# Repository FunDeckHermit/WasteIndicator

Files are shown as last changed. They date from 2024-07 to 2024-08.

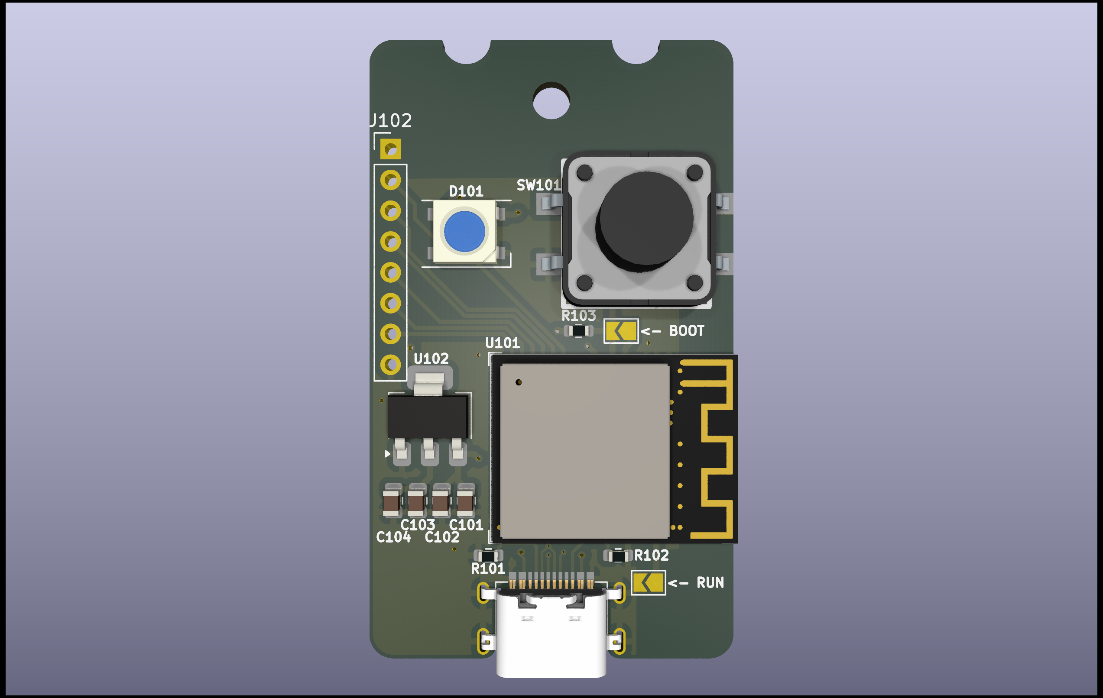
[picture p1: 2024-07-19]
KiCAD files/Exports/Waste Indicator Front.png

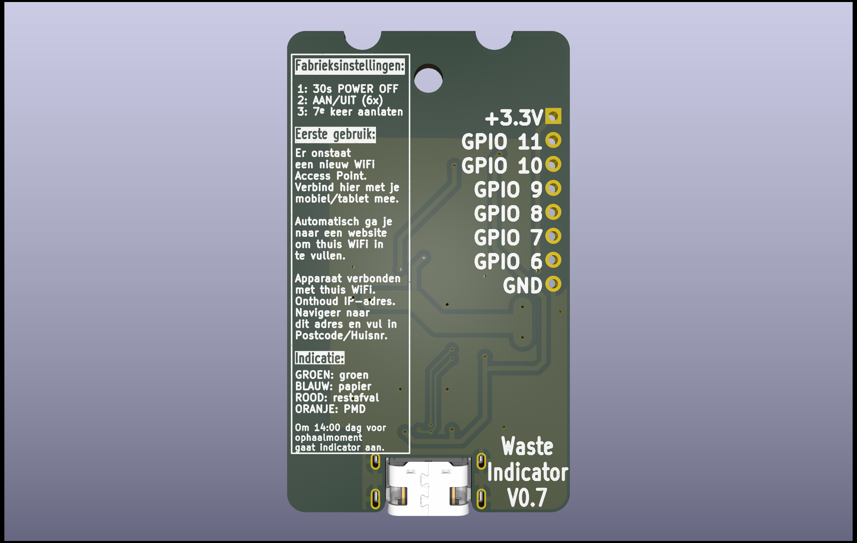
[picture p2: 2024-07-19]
KiCAD files/Exports/Waste Indicator Back.png

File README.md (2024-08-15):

# Waste Indicator
Scripts that modify Tasmota to interact with the Ximmio waste API. The color of an LED is set the day before a pickup date. It should also be easy to integrate into Home Assistant. 




## What it does:
* Sets the color of an RGB LED on the day before a pickup date
* Hides the RGB LED controls from Tasmota's main page
* Adds a form to set home adres
* Queries Ximmio's API to get the uniqueID of the adres
* Queries pickup dates every 12 hours
* Add a button to turn the LED off
* Save configuration during reset
* Reset configuration when holding button 8 seconds

## To-do
* Integrate into Home Assistant
* Don't use the companyCode of my local waste collector
* Test with a Tasmota compatible RGB light bulb
* Blink LED on first boot

# How to flash
Use a Webserial based ESP32 flasher or use ESPtool from the command line to flash the PCB.
First solder the "Boot" jumper, then hold the button to get the ESP32 into boot mode.

`esptool --port /dev/ttyACM0 erase_flash`   
`esptool --port /dev/ttyACM0 write_flash 0x0 tasmota32s2.factory.bin`

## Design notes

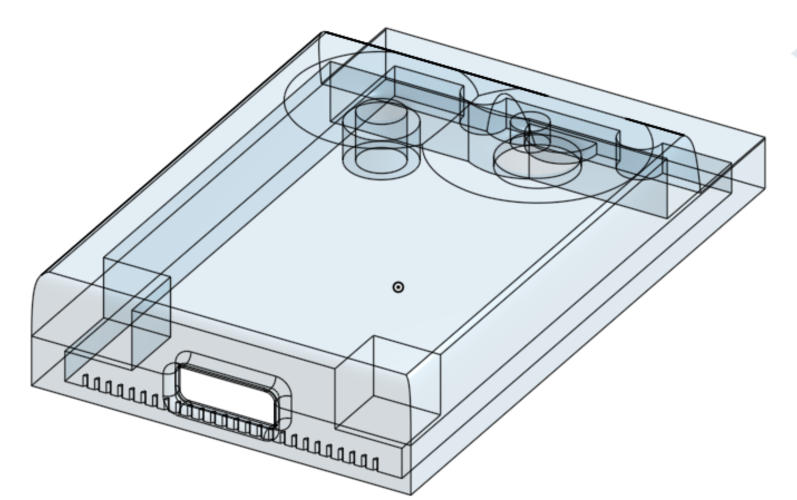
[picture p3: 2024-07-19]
OnShape Housing/Housing.png

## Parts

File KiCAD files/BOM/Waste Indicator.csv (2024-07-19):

Designator | Comment | Footprint | MF | MP | Quantity
C101, C102, C103, C104 | 1uF | C_0805_2012Metric | TAIYO YUDEN | MSASU21GSB7105KTNA01 | 4
R101, R102, R103 | 5K1 | R_0603_1608Metric | YAGEO | RC0603FR-075K1L | 3
D101 | SK6812 | LED_SK6812_PLCC4_5.0x5.0mm_P3.2mm | Adafruit | 1655 | 1
U101 | ESP32-S2-MINI-1 | ESP32-S2-MINI-1 | Esperrif | ESP32-S2-MINI-1-N4R2 | 1
U102 | AMS1117-3.3 | SOT-223-3_TabPin2 |  |  | 1
SW101 | 4,30172E+11 | btn_momentary_430172085816 | Wurth Elektronik | 4,30172E+11 | 1
J101 | USB4500-03-0-A | USB_C_Receptacle_USB4500-03-0-A | Global Connector Technology | USB4500-03-0-A | 1
J102 | Conn_01x08_Socket | PinHeader_1x08_P2.54mm_Vertical |  |  | 1

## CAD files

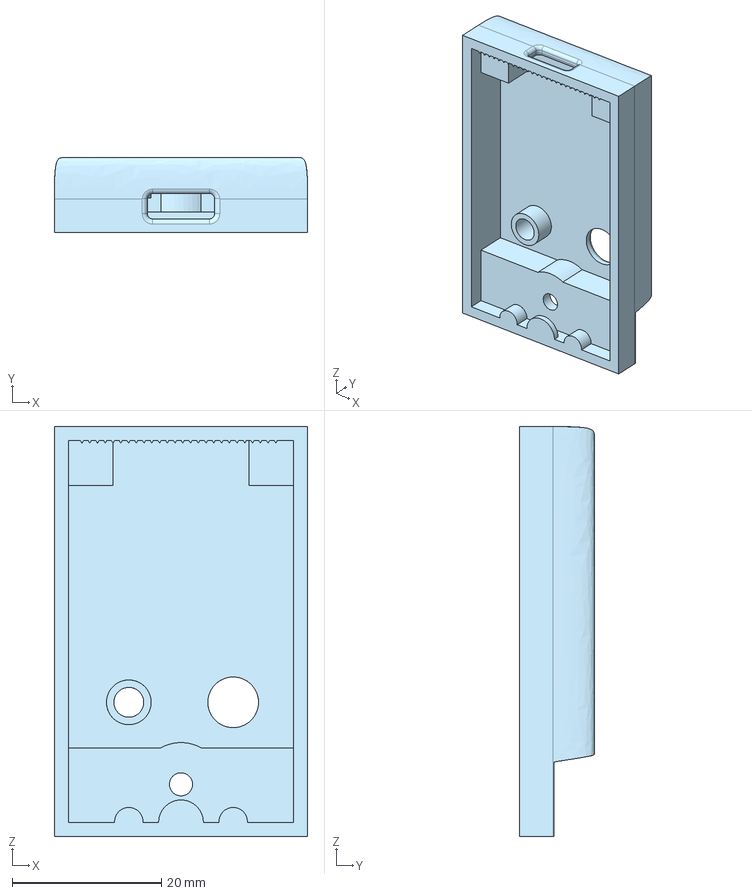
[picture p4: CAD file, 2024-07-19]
OnShape Housing/Housing.step
34.0 x 10.0 x 55.0 mm

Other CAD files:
OnShape Housing/Housing.stl

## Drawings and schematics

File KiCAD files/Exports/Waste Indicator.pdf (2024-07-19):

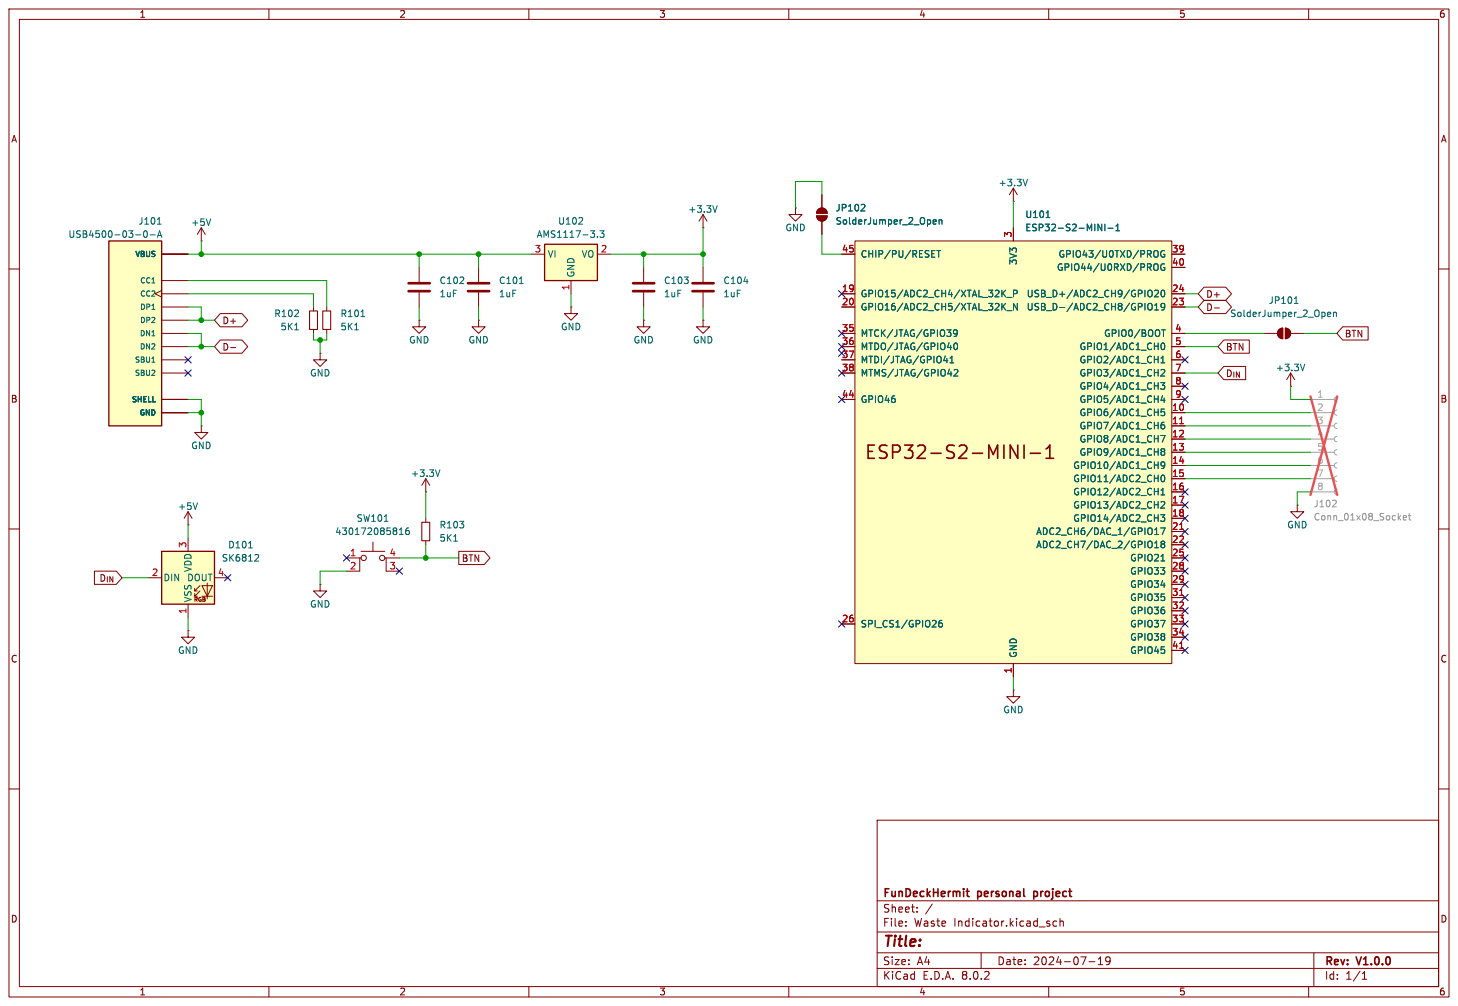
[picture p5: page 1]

3 GPIO35 31 GPIO36 32 GPIO37 33 GPIO38 34 MTCK/JTAG/GPIO39 35 MTDO/JTAG/GPIO40 36 MTDI/JTAG/GPIO41 37 MTMS/JTAG/GPIO42 38 GPIO43/U0TXD/PROG 39 GPIO0/BOOT 4 GPIO44/U0RXD/PROG 40 GPIO45 41 GPIO1/ADC1_CH0 5 GPIO2/ADC1_CH1 6 GPIO3/ADC1_CH2 7 GPIO4/ADC1_CH3 8 GPIO5/ADC1_CH4 9 U101 ESP32-S2-MINI-1 +5VGND GND GND

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

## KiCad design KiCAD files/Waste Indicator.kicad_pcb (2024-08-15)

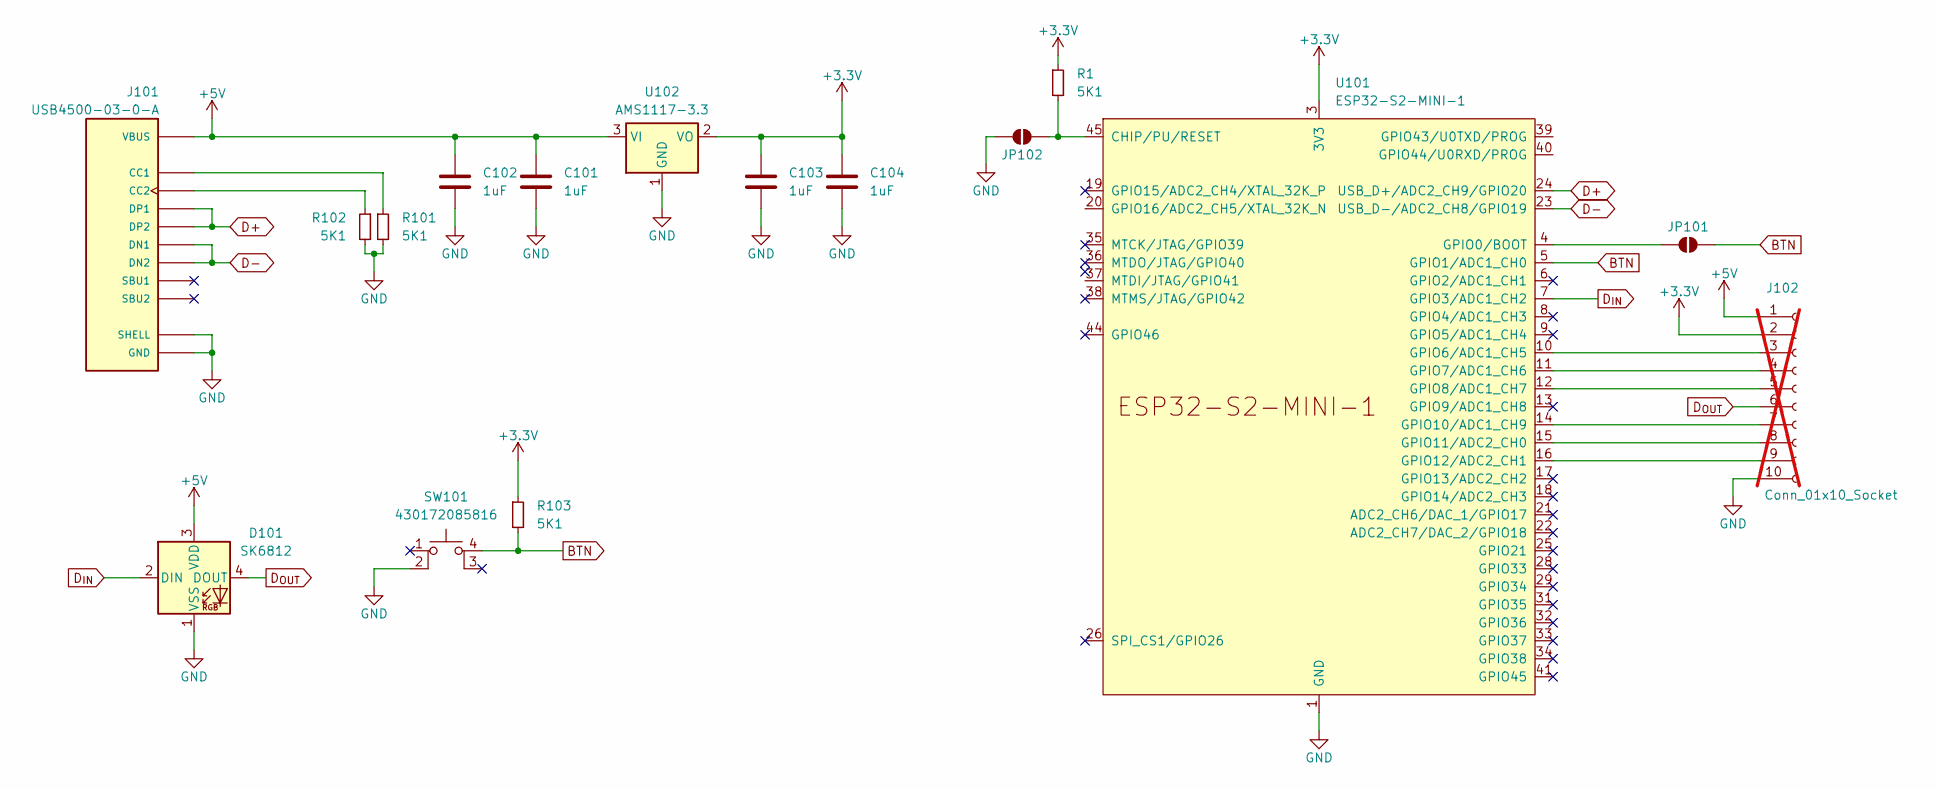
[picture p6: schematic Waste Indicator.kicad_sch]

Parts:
C101, C102, C103, C104: 1uF; C_0805_2012Metric
D101: SK6812; LED_SK6812_PLCC4_5.0x5.0mm_P3.2mm
J101: USB4500-03-0-A; USB_C_Receptacle_USB4500-03-0-A
J102: Conn_01x10_Socket; PinHeader_1x10_P2.54mm_Vertical; not fitted
JP101, JP102: SolderJumper_2_Open; SolderJumper-2_P1.3mm_Open_TrianglePad1.0x1.5mm
R1, R101, R102, R103: 5K1; R_0603_1608Metric
SW101: 430172085816; btn_momentary_430172085816
U101: ESP32-S2-MINI-1
U102: AMS1117-3.3; SOT-223-3_TabPin2

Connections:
+3.3V: C103.1, C104.1, J102.2, R1.1, R103.1, U101.3 (3V3), U102.2 (VO)
+5V: C101.1, C102.1, D101.3 (VDD), J101.A4 (VBUS), J101.A9 (VBUS), J101.B4 (VBUS), J101.B9 (VBUS), J102.1, U102.3 (VI)
BTN: JP101.2 (B), R103.2, SW101.4, U101.5 (GPIO1/ADC1_CH0)
D+: J101.A6 (DP1), J101.B6 (DP2), U101.24 (USB_D+/ADC2_CH9/GPIO20)
D-: J101.A7 (DN1), J101.B7 (DN2), U101.23 (USB_D-/ADC2_CH8/GPIO19)
D_{IN}: D101.2 (DIN), U101.7 (GPIO3/ADC1_CH2)
D_{OUT}: D101.4 (DOUT), J102.6
GND: C101.2, C102.2, C103.2, C104.2, D101.1 (VSS), J101.A1 (GND), J101.A12 (GND), J101.B1 (GND), J101.B12 (GND), J101.S1 (SHELL), J102.10, JP102.2 (B), R101.2, R102.2, SW101.2, U101.1 (GND), U101.2 (GND), U101.30 (GND), U101.42 (GND), U101.43 (GND), U101.46 (GND), U101.47 (GND), U101.48 (GND), U101.49 (GND), U101.50 (GND), U101.51 (GND), U101.52 (GND), U101.53 (GND), U101.54 (GND), U101.55 (GND), U101.56 (GND), U101.57 (GND), U101.58 (GND), U101.59 (GND), U101.60 (GND), U101.61 (GND), U101.62 (GND), U101.63 (GND), U101.64 (GND), U101.65 (GND), U102.1 (GND)
unnamed: J101.A5 (CC1), R101.1
unnamed: J101.B5 (CC2), R102.1
unnamed: J102.3, U101.10 (GPIO6/ADC1_CH5)
unnamed: J102.4, U101.11 (GPIO7/ADC1_CH6)
unnamed: J102.5, U101.12 (GPIO8/ADC1_CH7)
unnamed: J102.7, U101.14 (GPIO10/ADC1_CH9)
unnamed: J102.8, U101.15 (GPIO11/ADC2_CH0)
unnamed: J102.9, U101.16 (GPIO12/ADC2_CH1)
unnamed: JP101.1 (A), U101.4 (GPIO0/BOOT)
unnamed: JP102.1 (A), R1.2, U101.45 (CHIP/PU/RESET)

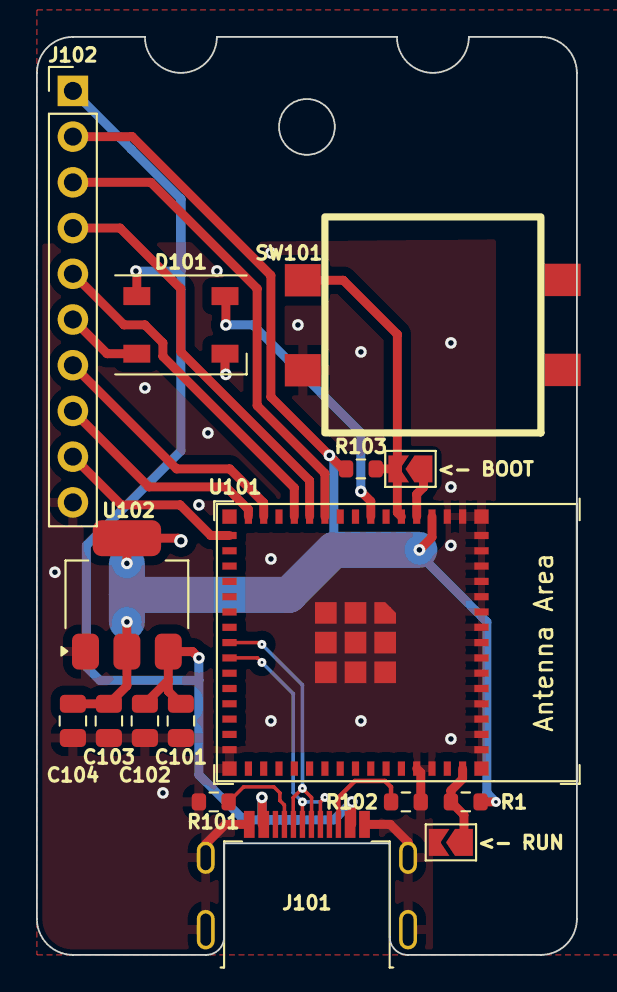
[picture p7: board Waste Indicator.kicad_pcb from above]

Board: 2 copper layers, 30.0 x 51.0 mm, 16 parts (0 on the bottom side), 18 nets.

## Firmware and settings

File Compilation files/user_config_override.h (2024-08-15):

/*
  user_config_override.h - user configuration overrides my_user_config.h for Tasmota

  Copyright (C) 2021  Theo Arends

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
  You should have received a copy of the GNU General Public License
  along with this program.  If not, see <http://www.gnu.org/licenses/>.
*/

#ifndef _USER_CONFIG_OVERRIDE_H_
#define _USER_CONFIG_OVERRIDE_H_

/*****************************************************************************************************\
 * USAGE:
 *   To modify the stock configuration without changing the my_user_config.h file:
 *   (1) copy this file to "user_config_override.h" (It will be ignored by Git)
 *   (2) define your own settings below
 *
 ******************************************************************************************************
 * ATTENTION:
 *   - Changes to SECTION1 PARAMETER defines will only override flash settings if you change define CFG_HOLDER.
 *   - Expect compiler warnings when no ifdef/undef/endif sequence is used.
 *   - You still need to update my_user_config.h for major define USE_MQTT_TLS.
 *   - All parameters can be persistent changed online using commands via MQTT, WebConsole or Serial.
\*****************************************************************************************************/

//#define FIRMWARE_LITE

#undef  MY_LANGUAGE
#define MY_LANGUAGE            nl_NL           // Dutch in the Nederland

#undef MQTT_BUTTONS
#define MQTT_BUTTONS           true

#undef KEY_HOLD_TIME
#define KEY_HOLD_TIME 8

#undef APP_BLINKTIME
#define APP_BLINKTIME 3

#undef  USE_HOME_ASSISTANT
#define USE_HOME_ASSISTANT

#undef HOME_ASSISTANT_DISCOVERY_PREFIX
#define HOME_ASSISTANT_DISCOVERY_PREFIX   "homeassistant"  // Home Assistant discovery prefix

#undef HOME_ASSISTANT_LWT_TOPIC
#define HOME_ASSISTANT_LWT_TOPIC   "homeassistant/status"  // home Assistant Birth and Last Will Topic (default = homeassistant/status)

#undef HOME_ASSISTANT_LWT_SUBSCRIBE
#define HOME_ASSISTANT_LWT_SUBSCRIBE    true               // Subscribe to Home Assistant Birth and Last Will Topic (default = true)

#undef USE_WS2812_HARDWARE
#define USE_WS2812_HARDWARE  NEO_HW_SK6812

#undef USE_WS2812_CTYPE
#define USE_WS2812_CTYPE     NEO_GRBW

#undef USE_BERRY_DEBUG
#define USE_BERRY_DEBUG

#undef USER_TEMPLATE
#define USER_TEMPLATE "{\"NAME\":\"Vuilnis Indicator\",\"GPIO\":[32,1,1,1376,1,1,1,1,1,1,1,1,1,1,1,1,0,1,1,1,0,1,1,1,0,0,0,0,1,1,1,1,1,0,0,1],\"FLAG\":0,\"BASE\":1}"  // [Template] Set JSON template

#undef MODULE
#define MODULE USER_MODULE

#undef FALLBACK_MODULE
#define FALLBACK_MODULE USER_MODULE

#undef PROJECT
#define PROJECT "VuilnisIndicator"

#endif  // _USER_CONFIG_OVERRIDE_H_

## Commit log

2024-07-19 Added KiCAD and OnShape files
    [Housing.step, Housing.stl, Waste Indicator.csv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]
2024-08-15 Fixed PCB to V1.0
    [Waste Indicator.kicad_pcb, Waste Indicator.kicad_sch]

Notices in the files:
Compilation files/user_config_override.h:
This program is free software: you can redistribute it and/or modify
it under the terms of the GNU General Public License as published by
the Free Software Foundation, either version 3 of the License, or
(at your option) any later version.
